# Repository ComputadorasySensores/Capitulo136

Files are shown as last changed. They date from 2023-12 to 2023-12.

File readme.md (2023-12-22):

# Pico Carrier Relay

Un placa de desarrollo para Raspberry Pi Pico/W con 3 canales de relé (relay) incorporados controlado mediante GPIOs y borneras para una fácil conexión a circuitos externos de continua y alterna.
También expone todos los GPIO de la placa para una fácil conexión de dispositivos adicionales y un pulsador de reset.

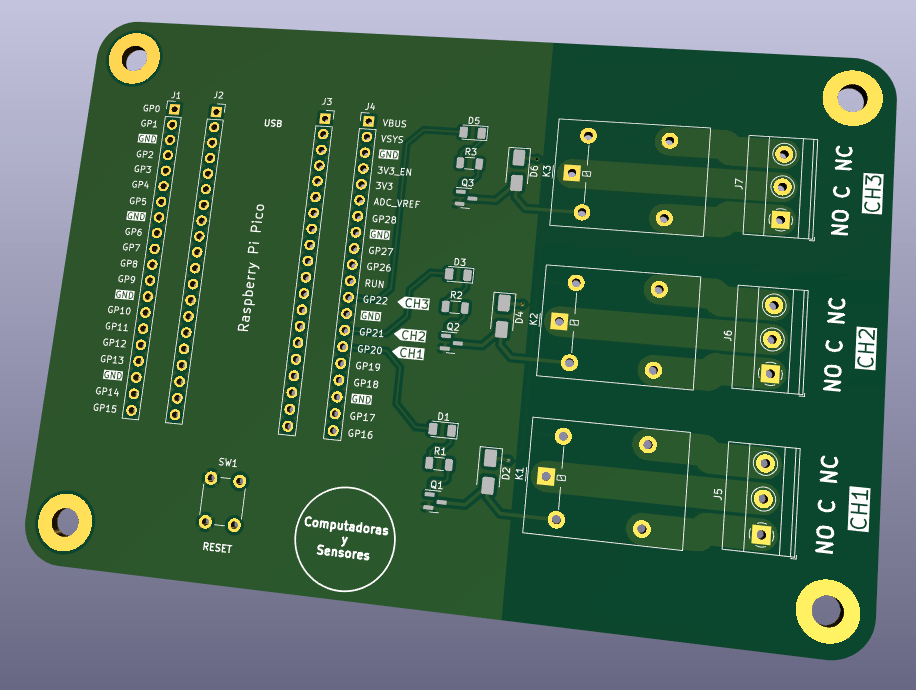
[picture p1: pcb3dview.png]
PCB3DView


Todos los archivos de diseño en Kicad se encuentran publicados junto a un código de ejemplo en MicroPython

# Fabricación

Dentro de la carpeta `fab` encontrarás el archivo `Pico-Carrier-Relay-Fab.zip` que incluye los Gerber y archivos de perforación .drl todo listo para ordenar a tu fabricante de PCB favorito.
Para solicitar el servicio de ensamble (PCBA) en dicha carpeta `fab` encontrarás el archivo `Pico-Carrier-Relay-BOM.csv` con el listado de materiales (BOM) y el archivo `Pico-Carrier-Relay-PnP.zip` para las coordenadas
de ubicación de componentes PnP (Pick and Place).

# Paso a paso

La explicación completa la podrás ver en el siguiente video de Youtube:
https://youtu.be/5ypWmVE0PGM

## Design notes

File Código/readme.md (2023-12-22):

# Programa de ejemplo

El programa de ejemplo `servidor_web.py` ejecuta un servidor web en la Pico W que muestra una página y botones para el accionamiento individual de cada uno de los canales.
No requiere de librerías adicionales, solo completar ssid y password de tu conexión local de WiFi.

# Paso a paso

La explicación completa la podrás ver en el siguiente video de Youtube:
https://youtu.be/5ypWmVE0PGM

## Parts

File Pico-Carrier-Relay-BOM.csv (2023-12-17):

Item # | Designator | Qty | Manufacturer | Mfg Part # | Description/Value | Package/Footprint | Type
1 | J1,J4 | 2 | Molex | 22-28-4200 | Through hole pin header THT 1x20 2.54mm single row |  | thru-hole
2 | D3,D5,D1 | 3 | Dialight | 598-8210-102F | LED RED CLEAR 1206 | 1206 | smd
3 | D4,D6,D2 | 3 | Onsemi | NRVA4007T3G | Diode 1000 V 1A Surface Mount SMA | SMA | smd
4 | J6,J5,J7 | 3 | Phoenix contact | 1715035 | TerminalBlock Phoenix MKDS-1,5-3 1x03 P5.00mm |  | thru-hole
5 | R3,R1,R2 | 3 | Panasonic | ERJ-8GEYJ111V | ±5% 0.25W, 1/4W Chip Resistor 1206 (3216 Metric) 110R | 1206 | smd
6 | K3,K1,K2 | 3 | Songle Relay | SRD-05VDC-SL-C | 5V 10A SPDT (1 Form C) 5 Plugin,15.6x19.2mm Power Relay |  | thru-hole
7 | J2,J3 | 2 | Molex | 90147-1120 | Through hole pin socket THT 1x20 2.54mm single row |  | thru-hole
8 | Q1,Q2,Q3 | 3 | Onsemi | MMBT3904 | Bipolar Transistor - BJT SOT-23 NPN | SOT-23-3 | smd
9 | SW1 | 1 | Omron | B3F-1000 | Tactile Switch 6X6 Flat 4.3mm Btn Force 100g |  | thru-hole

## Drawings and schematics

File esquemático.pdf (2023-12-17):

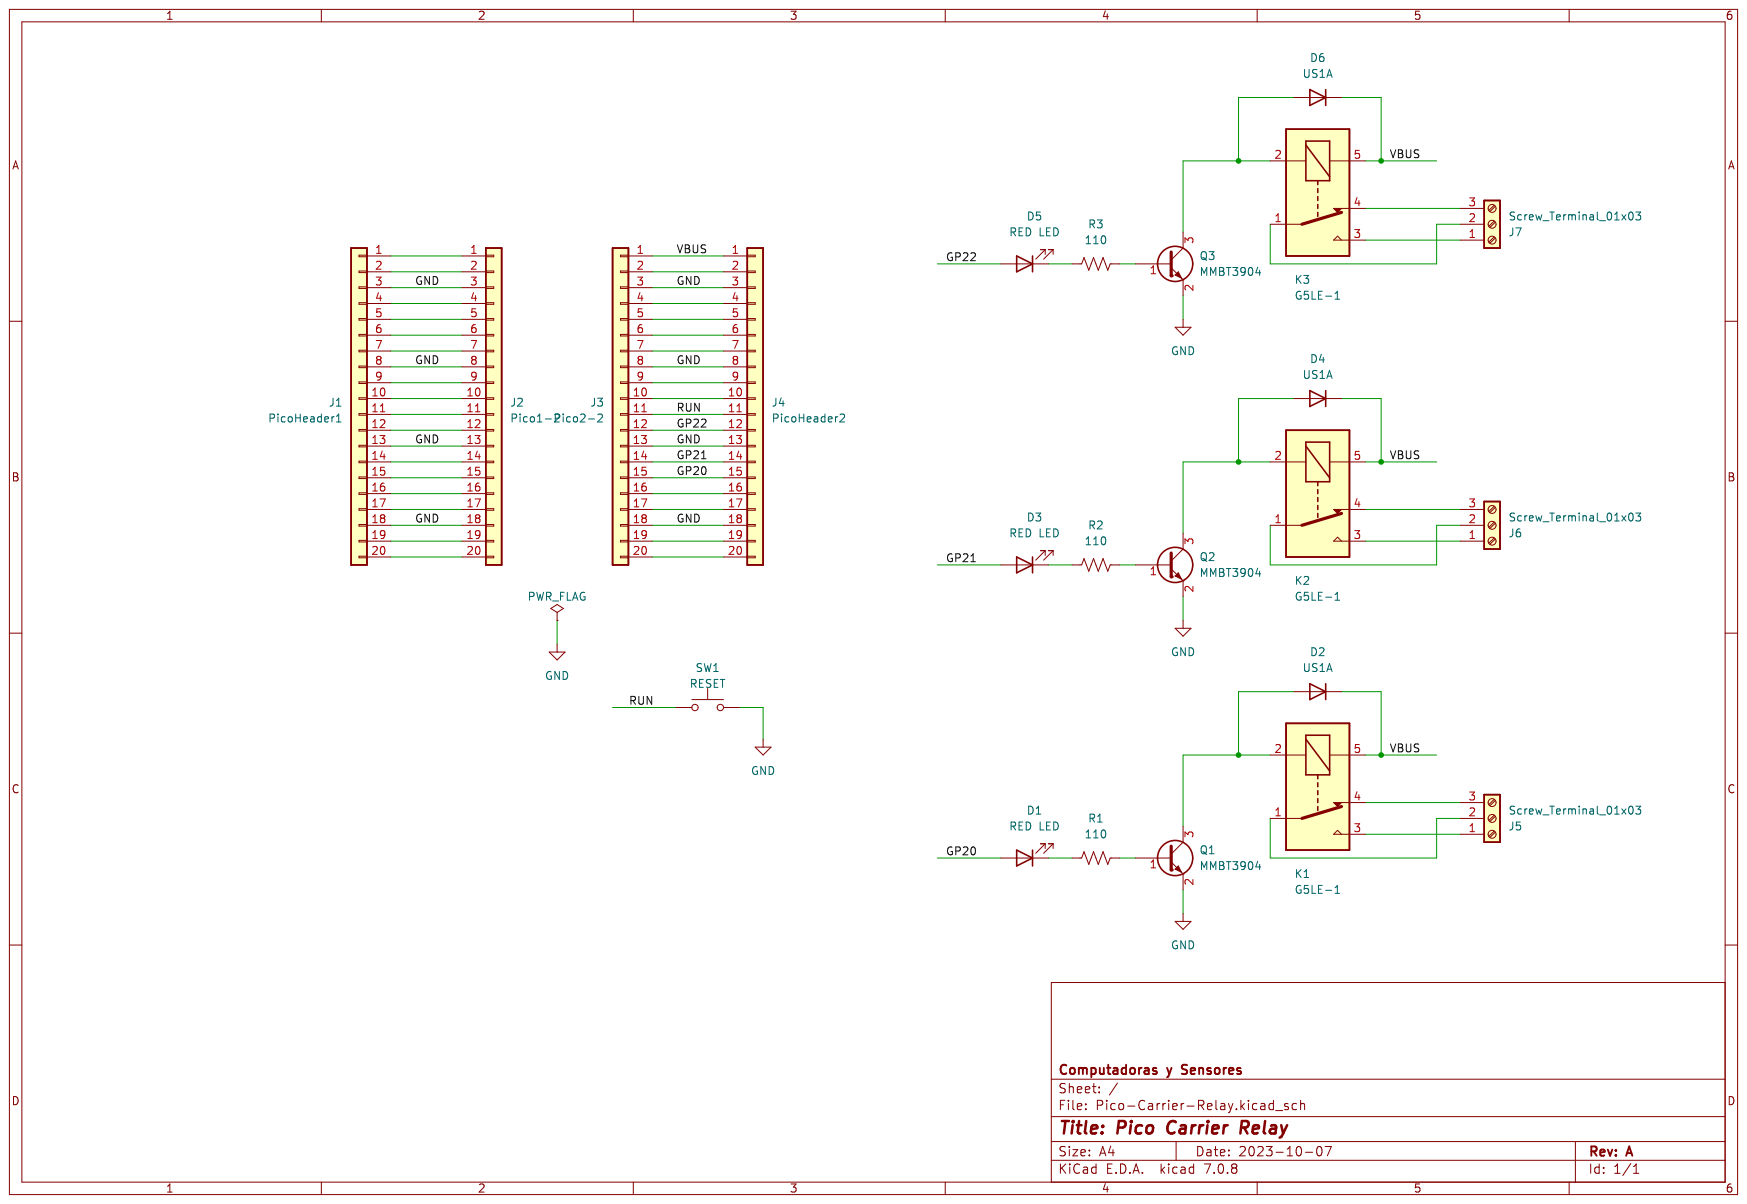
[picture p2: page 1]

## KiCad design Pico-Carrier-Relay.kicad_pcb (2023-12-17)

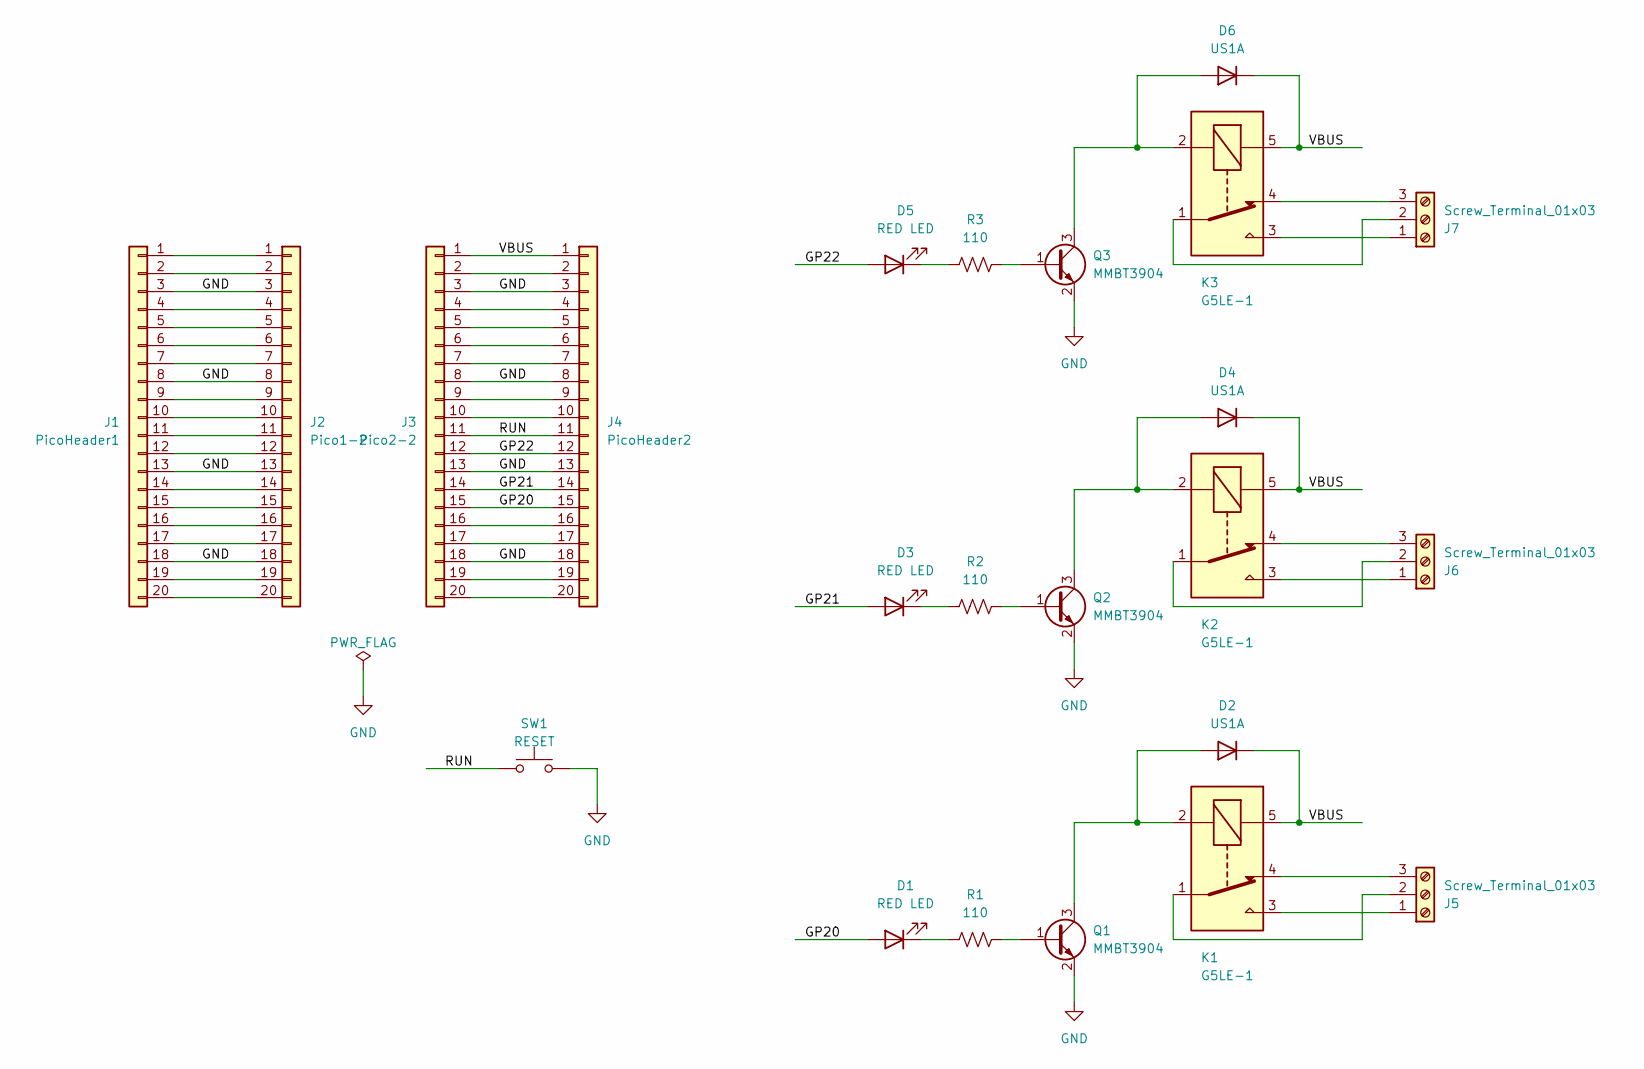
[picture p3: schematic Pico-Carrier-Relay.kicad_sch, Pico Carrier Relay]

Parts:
D1, D3, D5: RED LED; LED_1206_3216Metric
D2, D4, D6: US1A; D_SMA
J1: PicoHeader1; PinHeader_1x20_P2.54mm_Vertical
J2: Pico1-2; PinSocket_1x20_P2.54mm_Vertical
J3: Pico2-2; PinSocket_1x20_P2.54mm_Vertical
J4: PicoHeader2; PinHeader_1x20_P2.54mm_Vertical
J5, J6, J7: Screw_Terminal_01x03; TerminalBlock_Phoenix_MKDS-1,5-3_1x03_P5.00mm_Horizontal
K1, K2, K3: G5LE-1; Relay_SPDT_Omron-G5LE-1
Q1, Q2, Q3: MMBT3904; SOT-23
R1, R2, R3: 110; R_1206_3216Metric
SW1: RESET; SW_PUSH_6mm

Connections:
/GP20: D1.2 (A), J3.15, J4.15
/GP21: D3.2 (A), J3.14, J4.14
/GP22: D5.2 (A), J3.12, J4.12
/RUN: J3.11, J4.11, SW1.1
/VBUS: D2.1 (K), D4.1 (K), D6.1 (K), J3.1, J4.1, K1.5, K2.5, K3.5
GND: J1.3, J1.8, J1.13, J1.18, J2.3, J2.8, J2.13, J2.18, J3.3, J3.8, J3.13, J3.18, J4.3, J4.8, J4.13, J4.18, Q1.2 (E), Q2.2 (E), Q3.2 (E), SW1.2
unnamed: D1.1 (K), R1.1
unnamed: D2.2 (A), K1.2, Q1.3 (C)
unnamed: D3.1 (K), R2.1
unnamed: D4.2 (A), K2.2, Q2.3 (C)
unnamed: D5.1 (K), R3.1
unnamed: D6.2 (A), K3.2, Q3.3 (C)
unnamed: J1.1, J2.1
unnamed: J1.2, J2.2
unnamed: J1.4, J2.4
unnamed: J1.5, J2.5
unnamed: J1.6, J2.6
unnamed: J1.7, J2.7
unnamed: J1.9, J2.9
unnamed: J1.10, J2.10
unnamed: J1.11, J2.11
unnamed: J1.12, J2.12
unnamed: J1.14, J2.14
unnamed: J1.15, J2.15
unnamed: J1.16, J2.16
unnamed: J1.17, J2.17
unnamed: J1.19, J2.19
unnamed: J1.20, J2.20
unnamed: J3.2, J4.2
unnamed: J3.4, J4.4
unnamed: J3.5, J4.5
unnamed: J3.6, J4.6
unnamed: J3.7, J4.7
unnamed: J3.9, J4.9
unnamed: J3.10, J4.10
unnamed: J3.16, J4.16
unnamed: J3.17, J4.17
unnamed: J3.19, J4.19
unnamed: J3.20, J4.20
unnamed: J5.1, K1.3
unnamed: J5.2, K1.1
unnamed: J5.3, K1.4
unnamed: J6.1, K2.3
unnamed: J6.2, K2.1
unnamed: J6.3, K2.4
unnamed: J7.1, K3.3
unnamed: J7.2, K3.1
unnamed: J7.3, K3.4
unnamed: Q1.1 (B), R1.2
unnamed: Q2.1 (B), R2.2
unnamed: Q3.1 (B), R3.2

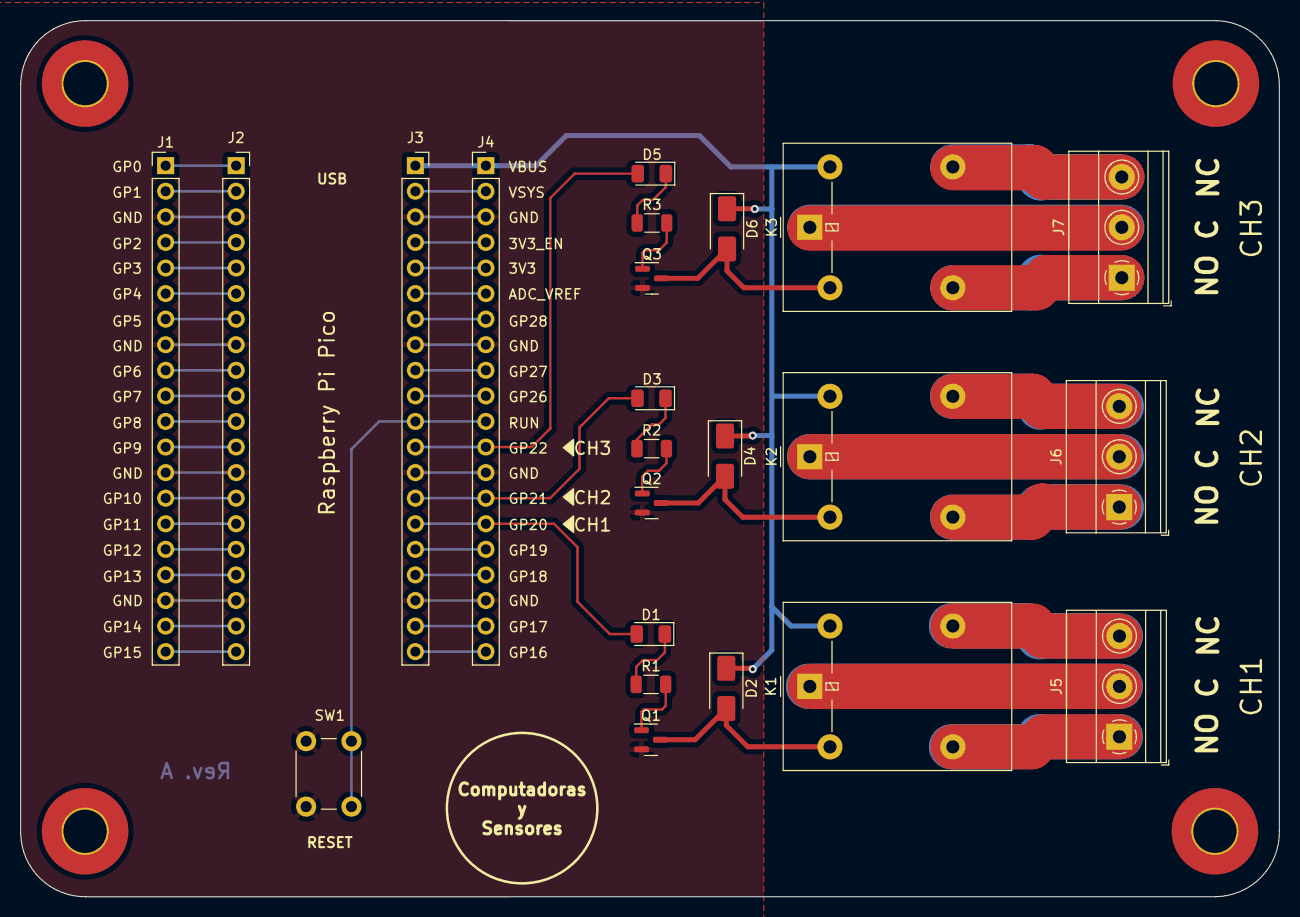
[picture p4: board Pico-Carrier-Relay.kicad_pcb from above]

Board: 2 copper layers, 125.0 x 87.0 mm, 23 parts (0 on the bottom side), 51 nets.

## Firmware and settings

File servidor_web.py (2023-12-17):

import network
import socket
from time import sleep
import machine
from machine import Pin

ssid = 'tu_ssid'
password = 'tu_password'

CH1 = Pin(20, Pin.OUT)
CH2 = Pin(21, Pin.OUT)
CH3 = Pin(22, Pin.OUT)

def CH1_ON():
    CH1.value(1)
    
def CH1_OFF():
    CH1.value(0)

def CH2_ON():
    CH2.value(1)
    
def CH2_OFF():
    CH2.value(0)
    
def CH3_ON():
    CH3.value(1)
    
def CH3_OFF():
    CH3.value(0)

    
def conectar():
    red = network.WLAN(network.STA_IF)
    red.active(True)
    red.connect(ssid, password)
    while red.isconnected() == False:
        print('Conectando ...')
        sleep(1)
    ip = red.ifconfig()[0]
    print(f'Conectado con IP: {ip}')
    return ip
    
def open_socket(ip):
    address = (ip, 80)
    connection = socket.socket()
    connection.bind(address)
    connection.listen(1)
    return connection

def pagina_web():
    html = f"""
            <!DOCTYPE html>
            <html>
            <head>
            </head>
            <body>
            <center>
            <table>
            <tr>
            <th>CH1</th>
            <th>CH2</th>
            <th>CH3</th>
            </tr>
            <tr>
            <td><form action="./CH1_ON">
            <input type="submit" value="ON" style="background-color: #FF0000; border-radius: 15px; height:120px; width:120px; border: none; color: white; padding: 16px 24px; margin: 4px 2px"/>
            </form></td>
            <td><form action="./CH2_ON">
            <input type="submit" value="ON" style="background-color: #FF0000; border-radius: 15px; height:120px; width:120px; border: none; color: white; padding: 16px 24px; margin: 4px 2px"/>
            </form></td>
            <td><form action="./CH3_ON">
            <input type="submit" value="ON" style="background-color: #FF0000; border-radius: 15px; height:120px; width:120px; border: none; color: white; padding: 16px 24px; margin: 4px 2px"/>
            </form></td>
            </tr>
            <tr>
            <td><form action="./CH1_OFF">
            <input type="submit" value="OFF" style="background-color: #04AA6D; border-radius: 15px; height:120px; width:120px; border: none; color: white; padding: 16px 24px; margin: 4px 2px"/>
            </form></td>
            <td><form action="./CH2_OFF">
            <input type="submit" value="OFF" style="background-color: #04AA6D; border-radius: 15px; height:120px; width:120px; border: none; color: white; padding: 16px 24px; margin: 4px 2px"/>
            </form></td>
            <td><form action="./CH3_OFF">
            <input type="submit" value="OFF" style="background-color: #04AA6D; border-radius: 15px; height:120px; width:120px; border: none; color: white; padding: 16px 24px; margin: 4px 2px"/>
            </form></td>
            </tr>
            </table>
            </center>
            </body>
            </html>
            """
    return str(html)

def serve(connection):
    while True:
        cliente = connection.accept()[0]
        peticion = cliente.recv(1024)
        peticion = str(peticion)
        try:
            peticion = peticion.split()[1]
        except IndexError:
            pass
        if peticion == '/CH1_ON?':
            CH1_ON()
        elif peticion =='/CH1_OFF?':
            CH1_OFF()
        elif peticion =='/CH2_ON?':
            CH2_ON()
        elif peticion =='/CH2_OFF?':
            CH2_OFF()
        elif peticion =='/CH3_ON?':
            CH3_ON()
        elif peticion =='/CH3_OFF?':
            CH3_OFF()
        html = pagina_web()
        cliente.send(html)
        cliente.close()

try:
    ip = conectar()
    connection = open_socket(ip)
    serve(connection)
except KeyboardInterrupt:
    pass

    
